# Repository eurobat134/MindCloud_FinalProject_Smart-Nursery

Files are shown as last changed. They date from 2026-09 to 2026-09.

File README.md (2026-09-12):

# Smart Nursery Guardian — PCB Design (Altium)

## Overview
4-layer PCB designed in Altium Designer for the Smart Nursery Guardian 
system. The board interfaces the STM32F401CEU6 microcontroller with all 
project sensors and actuators, and is manufactured-ready for JLCPCB.

---

## Project Files
- Power.SchDoc, Microcontroller.SchDoc, Sensors.SchDoc, Actuators.SchDoc   — Main schematics

- PCB1.PcbDoc   							   — PCB layout

- Power.SchLib, Microcontroller.SchLib, Sensors.SchLib, Actuators.SchLib   — Schematic symbols library

- PcbLib2.PcbLib   							   — PCB footprints library

---

## Layer Stackup
| Layer | Name | Type | Assigned Net |
|---|---|---|---|
| L1 | Top Signal | Signal | Component side |
| L2 | GND Plane | Plane  | GND |
| L3 | Power Plane  | Plane  | +3V3 / +5V |
| L4 | Bottom Signal| Signal | Routing |

Board thickness: 1.6mm
Copper weight: 1oz outer, 0.5oz inner

---

## Design Rules
Follows JLCPCB 4-layer manufacturing capabilities:
- Minimum trace width:     0.127mm
- Minimum clearance:       0.127mm
- Minimum via hole:        0.3mm
- Minimum via outer dia:   0.6mm
- Board edge clearance:    0.3mm
- Solder mask expansion:   0.051mm

Design rules file: 4layer-1oz.RUL
Source: github.com/ayberkozgur/jlcpcb-design-rules-stackups

---

## Microcontroller
STM32F401CEU6 — UFQFPN-48, QFN 7x7mm, 0.5mm pitch
- VCAP_1 (pin 22): 2.2uF to GND — mandatory for stable operation
- VSS-EP (pin 49): connected to GND plane (thermal pad)
- Crystal: 8MHz HSE with 22pF load caps

---

## Schematic Sections
1. Power Supply     — USB Micro-B + screw terminal, AMS1117-3.3 LDO
2. Microcontroller  — STM32 core, crystal, NRST, Boot0, decoupling
3. Sensors          — DHT11, LDR, MQ-9 gas sensor, PIR
4. Actuators        — L293D motor driver, servo, buzzer
5. LED Indicators   — RGB LED (header), room LED (header)
6. Debug & Comms    — SWD 5-pin header, UART header

---

## Power Architecture
Input:  5V via USB Micro-B or 2-pin screw terminal (5V/2A minimum)
3.3V:   Generated by AMS1117-3.3 LDO (SOT-223)
5V rail feeds: Servo, L293D motor supply, PIR, gas sensor
3.3V rail feeds: STM32, L293D logic, DHT11, LDR divider

---

## Key Component Notes
- L293D: SOIC-16 — all 4 GND pins (4,5,12,13) connected to GND plane
- MQ-9 gas sensor: powered from 5V, AOUT scaled via 10k/20k
  voltage divider before connecting to STM32 ADC (3.3V safe)
- DHT11: single-wire protocol on PA0, requires 4.7k pull-up to 3.3V
- USB D+/D-: routed as differential pair on L1 (Top)
  Width: 0.2mm, Gap: 0.2mm, targeting 90Ω differential impedance

---

## Supplier Information
All components include the following fields as per requested:
- Manufacturer
- Manufacturer Part Number (MPN)
- Supplier
- Supplier Part Number

---

## DRC Status
- Clearance violations:        0
- Trace width violations:      0
- Via violations:              0
- Silk to solder mask:         Suppressed (handled by manufacturer)
- Matched lengths:             Scoped to USB differential pair only

---

## How to Open
1. Open Altium Designer 26 or later
2. File > Open Project > select .PrjPcb
3. Open .SchDoc to review schematic
4. Open .PcbDoc for PCB layout
5. Design > Rules to review JLCPCB constraints
6. Run DRC to verify clean status before any modifications

---

## Notes
- Assembly notes layer is populated for all components

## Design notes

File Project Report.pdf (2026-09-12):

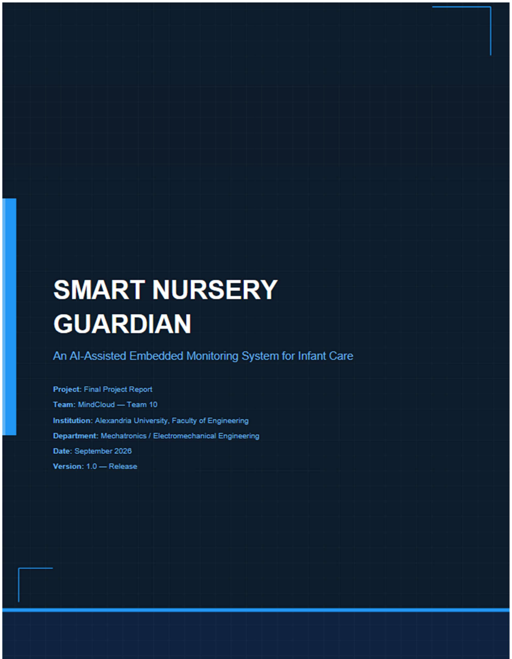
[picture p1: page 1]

## 1 PROJECT OVERVIEW

Smart Nursery Guardian addresses one of parenthood's most exhausting challenges: not knowing why an infant is crying. At 3 AM, with no contextual clues, distinguishing a hungry cry from a tired cry or a discomfort cry is nearly impossible. The system solves this by listening to the cry, classifying its cause using machine learning, and responding automatically — rocking the crib, adjusting lighting and cooling, and alerting caregivers to safety hazards. It operates like an attentive caregiver that never sleeps and never misses a signal.

The system combines machine learning running on a laptop with a real-time embedded microcontroller to monitor the nursery environment and react intelligently. Sensors track temperature, humidity, motion, light levels, and gas concentration. Actuators respond with crib rocking, cooling, lighting, and alerts — all driven by the classification result.

### Why This Project Matters

- Addresses sleep loss from misinterpreting infant cries — turning guesswork into data-backed guidance
- Realistic technical scope: signal processing, machine learning, real-time firmware, GUI design, and IoT
- Demonstrates the standard edge-device + smart-device IoT architecture used professionally

### System Components

Component | Location | Responsibility
Python App (Tkinter) | Laptop | Mic input, noise filter, cry detection, ML classification, GUI, Telegram alerts
ESP32 Firmware | Microcontroller | PIR, light, temperature, gas sensors; servo, buzzer, LED, fan control
Telegram Bot | Cloud (free) | Gas alert notifications to caregiver phone from any location

Split architecture rationale: AI and audio processing require Python's libraries and compute power. Real-time sensor and motor control require the MCU's low-level timing. Audio never crosses serial — giving zero-latency cry detection. Other sensors relay through the MCU over UART.

## 2 HARDWARE & PCB DESIGN

The hardware platform centers on the ESP 32 Developer Board. The PCB uses STM32F401CEU6 (UFQFPN-48, QFN 7x7mm, 0.5mm pitch) and a 4-layer JLCPCB-ready board transitioning the breadboard prototype into a manufacturable, assembly-ready product with full supplier information on every component.

### STM32F401CEU6 — Pin Assignment

Pin | Signal | Type | Connected To
PA0 | DHT11 Data | GPIO 1-Wire | DHT11 + 4.7k pull-up to 3.3V
PA1 | LDR ADC | ADC1_IN1 | LDR voltage divider (10k)
PA2 | Gas Sensor | ADC1_IN2 | MQ-x AOUT via 10k/20k divider
PA3 | PIR Signal | GPIO Input | HC-SR501 digital output
PA4-PA7 | RGB LED | GPIO Output | R/G/B channels via 330 ohm resistors
PA6 | Servo PWM | TIM3_CH1 | 3-pin servo header (+5V)
PA9 / PA10 | UART TX/RX | USART1 | Laptop serial link (J7 header)
PA13 / PA14 | SWD Debug | SWD | 5-pin debug header (J2)
PB0 | Fan PWM | TIM3_CH3 | L293D ENABLE1 pin (fan speed)
PB1 | Room LED | GPIO Output | 330 ohm to 2-pin header J_LED
PB10 | Buzzer | GPIO Output | 3.3V active buzzer (direct drive)
PB12 / PB13 | Motor Direction | GPIO Output | L293D IN1 / IN2

### PCB Layer Stackup (4-Layer, 1.6mm, JLCPCB)

Layer | Name | Type | Net Assignment
L1 (Top) | Top Signal | Signal | Component placement + signal routing
L2 | GND Plane | Plane | Solid GND pour — no signal routing here
L3 | Power Plane | Plane | +3V3 and +5V copper pours (split plane)
L4 (Bottom) | Bot Signal | Signal | Secondary signal routing

### JLCPCB Design Rules Applied

Rule | Value | Rule | Value
Min trace width | 0.2mm | Min via hole | 0.3mm
Min clearance | 0.2mm | Via outer diameter | 0.6mm

USB diff. width | 0.2mm | USB diff. gap | 0.2mm
Board edge clearance | 0.3mm | Solder mask expansion | 0.051mm
Copper weight (outer) | 1 oz | Copper weight (inner) | 0.5 oz

## 3 MACHINE LEARNING PIPELINE

The ML subsystem runs entirely in Python on the laptop and classifies each detected cry as Hungry, Tired, or Discomfort. The trained model is loaded once at startup and classifies every new cry in real time without retraining. Audio is read directly from the laptop microphone and never crosses the serial link, ensuring zero-latency cry detection.

### 3.1 — Audio Processing Chain

Stage | Tool / Method | Purpose
1. Capture | PyAudio (rolling stream) | Continuous microphone input in chunks
2. Noise Reduction | noisereduce library | Spectral gating to remove hum, fans, background noise

### 3. Voice Activity

Detection | webrtcvad library | Confirm a real cry is present — avoid false triggers

### 4. Feature

Extraction | librosa | Extract numerical features from confirmed cry segment
5. Classification | scikit-learn | Random Forest predicts Hungry / Tired / Discomfort
6. Response | Tkinter GUI + PySerial | Display result, trigger hardware actions over UART

### 3.2 — Feature Extraction (Current)

Feature | Description | Output Dim.
MFCC (13 coefficients) | Tone color and spectral shape — mimics human
| auditory perception | 26 (mean+std)
Fundamental Frequency (F0) | Base pitch — infant cries range 400-600 Hz typically | 2 (mean+std)
RMS Energy | Average loudness and intensity of the cry | 1
Zero-Crossing Rate | Harshness and noisiness of the signal | 2 (mean+std)
Duration | Total length of the confirmed cry segment in seconds | 1

Start with MFCC alone — it performs close to best-published results by itself. Add other features and measure if accuracy actually improves. Do not add complexity without proof of benefit from the confusion matrix.

## 4 THE CLASS IMBALANCE PROBLEM

The Donate-A-Cry corpus (457 recordings) has a severe class imbalance that reflects reality — hungry cries genuinely occur more often than tired or discomfort cries. However, training a classifier directly on this raw distribution produces a model that is statistically impressive but practically useless: it learns to predict Hungry for everything and still achieves 89% accuracy.

### Dataset Distribution

Class | Recordings | Percent | Problem
Hungry | 382 | 84% | Model defaults to this — inflates overall accuracy
Discomfort | 27 | 6% | Severely under-represented in training
Tired | 24 | 5% | Nearly invisible to the classifier

### Current Model Results

The model achieves 89.66% overall accuracy — but this number is entirely misleading:

Class | Precision | Recall | F1-Score | Support | Assessment
Hungry | 0.90 | 1.00 | 0.94 | 77 | Over-predicted
Discomfort | 1.00 | 0.20 | 0.33 | 5 | Severely under-detected
Tired | 0.00 | 0.00 | 0.00 | 5 | NOT DETECTED AT ALL
Accuracy | | | 0.90 | 87
Macro Average | 0.63 | 0.40 | 0.43 | 87 | Critical failure point
Weighted Average | 0.85 | 0.90 | 0.86 | 87

Why 89.66% accuracy is misleading: a trivial model that always predicts "Hungry" scores 88.5%. The macro-average F1 of 0.43 is the honest metric — it weights all classes equally. Tired cries are never detected (F1 = 0.00) and Discomfort is barely caught (F1 = 0.33). Overall accuracy is not valid here.

### Data Augmentation — Applied Solution

Augmentation creates synthetic variants of minority-class recordings using acoustically valid transformations, applied to training data only. The test set is never augmented to preserve evaluation integrity.

Technique | Parameters | Why It Helps
Pitch Shift | +-2 semitones maximum | Prevents memorizing exact frequency signatures — pitch- invariant patterns
Time Stretch | 0.9x to 1.1x speed (pitch preserved) | Teaches cry-length invariance across different playback speeds

Noise Mixing | Light background noise overlay | Improves robustness to room acoustics and microphone variation

Split 80/20 before any augmentation begins. Augment only training data. Always evaluate using a per-class confusion matrix — not overall accuracy.

## 5 PROPOSED IMPROVED ARCHITECTURE

The core limitation of the current pipeline is that it discards all temporal structure. Summarizing an entire cry clip into a single mean-and-std vector loses how the cry evolves over time — yet that temporal evolution is precisely what distinguishes cry types. A tired cry starts strong and fades; a hungry cry escalates. None of this is captured in global statistics.

### 5.1 — 40ms Frame Extraction

Instead of one feature vector per clip, one MFCC frame is extracted every 40ms with 50% overlap. A 3-second cry produces approximately 75 frames — a 2D array of (time_steps x features) that preserves the temporal evolution of the cry. This is the fundamental change that unlocks the deeper architecture.

### 5.2 — CNN — Spatial Feature Extractor

1D convolutions across the time dimension detect local spectral micro-patterns: sharp onset, sustained vowel, rapid decay. These short-term acoustic fingerprints are richer and more discriminative than global MFCC statistics. The CNN processes each 40ms frame and outputs a learned feature representation for every time step in the sequence.

### 5.3 — LSTM — Temporal Context Modeling

The CNN-processed sequence feeds an LSTM which maintains a hidden state across all time steps, learning longrange dependencies — how the cry evolves over seconds. A tired cry that starts strong and fades produces a fundamentally different LSTM hidden state than a hungry cry that builds in intensity, even when individual frames look similar. This is the critical capability the current pipeline entirely lacks.

### 5.4 — Attention — Diagnostic Frame Selection

Not all 40ms frames are equally informative. The Attention layer assigns a learned weight to each time step — frames containing class-discriminative patterns receive high weight; noise frames receive near-zero weight. The final classification uses a weighted sum of LSTM outputs, making the model robust to cry length variation and to the positional differences in diagnostic moments between minority-class samples.

### Architecture Comparison

Factor | Current (Random Forest) | Proposed (CNN + LSTM + Attention)
Input representation | Single vector per clip | Sequence of 75+ 40ms frames
Temporal information | None — discarded entirely | Fully preserved via LSTM hidden state
Feature learning | Manual (MFCC statistics) | Learned automatically by CNN layers
Frame importance | All frames equal weight | Attention assigns weight by relevance
Augmentation benefit | Limited (global stats shift) | High — diverse frame-level sequences
Expected macro F1 | 0.30 - 0.43 (current result) | 0.75+ (published literature target)
Training requirement | Seconds on CPU | Minutes on GPU or Google Colab free tier

## 6 SYSTEM OPERATION FLOW

### Laptop Main Loop (Python)

Step | Action | Detail
1 | Capture | Continuous microphone audio in rolling chunks via PyAudio
2 | Filter | Spectral noise reduction using noisereduce library
3 | VAD | webrtcvad confirms real cry is present — prevents false triggers
4 | Signal MCU | Send CRY_DETECTED over UART — servo starts immediately
5 | Classify | Extract features and run through trained ML model
6 | Respond | Hungry: play video. Tired: sound buzzer. Discomfort: show message.
7 | Clear | Send CRY_ENDED when cry signal drops — stop servo

### Serial Message Protocol (UART 9600 baud)

Direction | Message | Trigger | Action Taken
MCU -> Laptop | BABY_AWAKE | 4+ PIR events in 8 seconds | Update GUI baby-awake state
MCU -> Laptop | GAS_ALERT | Gas sensor threshold exceeded | Show red full-screen alert + send Telegram
MCU -> Laptop | TEMP:<val> | Periodic every 5 seconds | Update temperature display in GUI
Laptop -> MCU | CRY_DETECTED | VAD confirms cry present | Start servo + enable LED cry-state logic
Laptop -> MCU | CRY_ENDED | Cry signal drops | Stop servo + clear LED cry-state
Laptop -> MCU | BUZZER_ON | Tired cry classified | Sound 3.3V active buzzer immediately

### Temperature Control Response Table

Temperature Range | RGB LED Color | Fan Speed | PWM Duty Cycle
Below 25 deg C | Blue | OFF | 0%
25 deg C to 30 deg C | Green | Half Speed | 50%
Above 30 deg C | Red | Full Speed | 100%

Fan and RGB LED are fully local decisions (temperature only — no laptop input needed). The room LED is the exception: it runs on the MCU but depends on cry-detected state from the laptop over UART.

## 7 SUMMARY & PROJECT STATUS

Smart Nursery Guardian successfully integrates machine learning, embedded systems, IoT communication, and real-time firmware into a cohesive infant monitoring platform. The 4-layer STM32F401CEU6 PCB is complete and DRC-validated. The Python pipeline achieves real-time cry classification and environmental monitoring with immediate hardware response across all sensor and actuator channels.

The primary open challenge is the macro-average F1 score of 0.30 to 0.43, caused entirely by class imbalance in the Donate-A-Cry corpus. The current Random Forest classifier fails to detect Tired cries (F1 = 0.00) and barely detects Discomfort (F1 = 0.33) despite 89.66% overall accuracy. The solution is fully defined: CNN + LSTM + Attention operating on 40ms frames, combined with continued data augmentation on minority classes.

### Deliverables Status

Deliverable | Status | Notes
STM32 Schematic (6 sections) | Complete | DRC clean, all nets labeled and cross- referenced
4-Layer PCB Layout | Complete | JLCPCB rules verified, DRC passed
Sensor and Actuator Firmware (HAL) | Complete | Breadboard prototype assembled and tested
Python ML Pipeline — RF Baseline | Complete | Deployed and classifying in real time
Data Augmentation | Complete | Pitch shift, time stretch, noise mixing applied
Telegram Gas Alert Simulation | Complete | BluePill simulation running in Proteus
CNN + LSTM + Attention Architecture | Proposed | Architecture fully defined, pending implementation

With the proposed CNN + LSTM + Attention upgrade and continued minority-class augmentation, the macro-average F1 score is expected to exceed 0.75 — transforming the system from a statistically accurate but classbiased tool into a genuinely reliable infant cry classifier that correctly detects Tired and Discomfort cries under real-world data imbalance.
